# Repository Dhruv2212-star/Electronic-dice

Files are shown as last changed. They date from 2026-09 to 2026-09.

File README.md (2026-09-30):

# Electronic Dice
Tired of Board game tactics and cheating???? 
**I present an ELECTRONIC dice**  
A small 30mm x  30mm module which has 6 LEDs. when u press a button it changes LEDs quickly and random leds turn on from 1-6.  

# How to use?? 
It's simple enough for a todler to use ! just press a button and you get a random no. of LEDs!  
**Final assembly image**  

Assembly

*You know what else is cool??*
the PCB, it uses minimal components at surface to keep it super clean!  

PCB 3d model image

# Firmware Flashing
connect your debugger probe to the J2 port accordingly for this first.  
Our Pinc connections on PCB  

| J2 pin | Signal | ATtiny84A |  
| -----: | --- | --- |
| 1 | VCC | U1 pin 1  |  
| 2 | GND | U1 pin 14 | 
| 3 | MOSI | PB0 |  
| 4 | MISO | PB1 | 
| 5 | SCK | PB2 | 
| 6 | RESET  | PB3 |  

**Install Arduino IDE**  
then,  
File-> prefrences  
-additional board manager URLs  
--https://drazzy.com/package_drazzy.com_index.json  
Tools->Boards->Board manager  
install "ATTinyCore"  

Select our board by: Tools-> Board-> ATTinny84a  
then set:  
| Arduino setting | Value |  
| --- | --- |
| Chip | **ATtiny84A** |  
| Clock | **1 MHz internal** |  
| B.O.D. | **Disabled** |  
| EEPROM | **Retained** |  
| Programmer | **USBasp** |  

**Connect USBasp**  
(power the pcb off first)  
connect: USBasp -> J2  
**Burn the config**  
**Upload dice firmware**  

# That's it !!

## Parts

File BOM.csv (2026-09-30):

ref | value | quantity | symbol | footprint | unit_price_inr | supplier | buy_link | extended_price_inr
U1 | ATtiny84A-SSU | 1 | MCU_Microchip_ATtiny:ATtiny84A-SS | Package_SO:SOIC-14_3.9x8.7mm_P1.27mm | 80.54 | Evelta | https://evelta.com/attiny84a-ssu-ic-mcu-8bit-8kb-flash-14soic/ | 80.54
D1-D6 | White LED 1206 | 6 | Device:LED | LED_SMD:LED_1206_3216Metric_Pad1.42x1.75mm_HandSolder | 0.8 | KTRON India | https://www.ktron.in/product/smd-white-led-1206-package/ | 4.800000000000001
R1-R6 | 1kΩ | 6 | Device:R | Resistor_SMD:R_1206_3216Metric | 3.0 | Probots | https://probots.co.in/1k-smd-resistor.html | 18.0
R7 | 10kΩ | 1 | Device:R | Resistor_SMD:R_1206_3216Metric | 3.0 | Probots | https://probots.co.in/10k-smd-resistor.html | 3.0
C1 | 100nF 50V | 1 | Device:C | Capacitor_SMD:C_1206_3216Metric | 1.82 | KTRON India | https://www.ktron.in/product/100nf-50v-104-mlcc-1206/ | 1.82
SW1 | 6x6x5mm tactile push button | 1 | Switch:SW_Push | Button_Switch_THT:SW_PUSH_6mm_H5mm | 1.0 | Techtonics | https://techtonics.in/product/tactile-push-button-switch-4-pin-6x6x5-pack-of-10/ | 1.0
J1 | 1x2 2.54mm male header | 1 | Connector_Generic:Conn_01x02 | Connector_PinHeader_2.54mm:PinHeader_1x02_P2.54mm_Vertical | 1.37 | Sharvi Electronics | https://sharvielectronics.com/product-category/component/components/connectors/berg_strip/ | 1.37
J2 | 1x6 2.54mm male header | 1 | Connector_Generic:Conn_01x06 | Connector_PinHeader_2.54mm:PinHeader_1x06_P2.54mm_Vertical | 2.3 | Sharvi Electronics | https://sharvielectronics.com/product-category/component/components/connectors/berg_strip/ | 2.3
TOTAL |  |  |  |  |  |  |  | 112.83

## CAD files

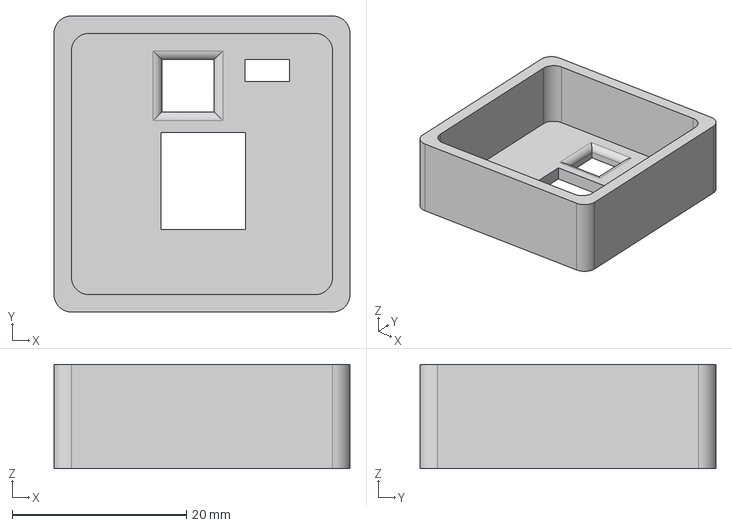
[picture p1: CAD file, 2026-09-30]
CAD/Top case.step
34.0 x 34.0 x 12.0 mm

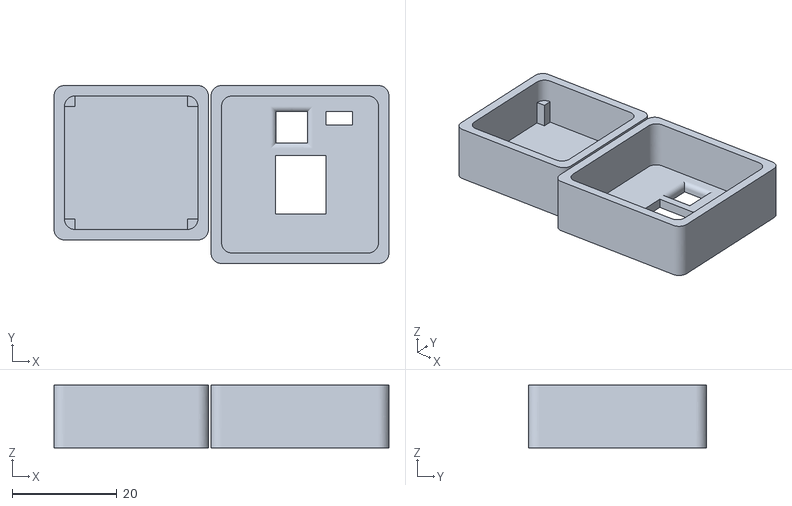
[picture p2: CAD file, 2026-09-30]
Production/Final case.stl
64.0 x 34.0 x 12.0

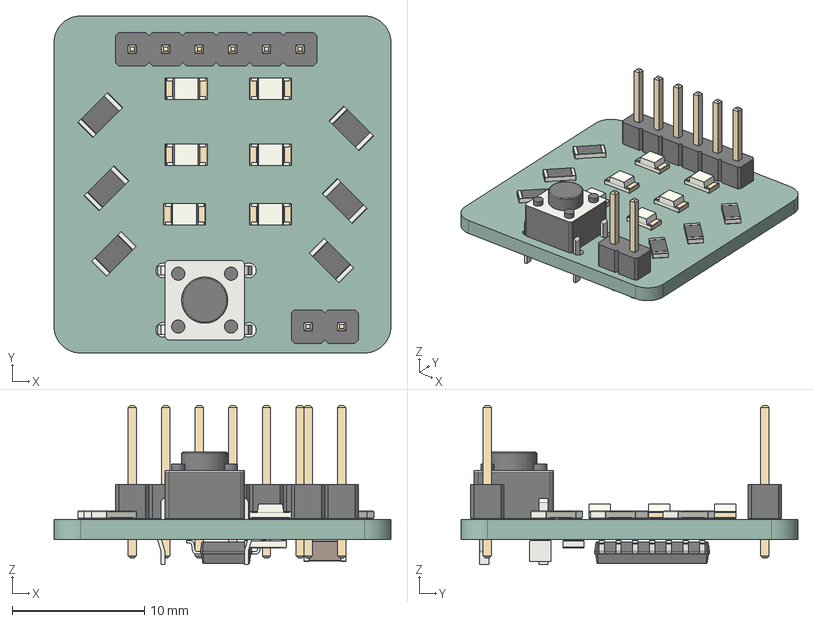
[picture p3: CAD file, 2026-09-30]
CAD/PCB model.step
25.5 x 25.5 x 12.0 mm
PinHeader_1x02_P254mm_Vertical
R_1206_3216Metric x 7
LED_1206_3216Metric x 6
SW_PUSH_6mm_h5mm
PinHeader_1x06_P254mm_Vertical
C_1206_3216Metric
SOIC-14_3.9x8.7mm_P1.27mm
module_PCB

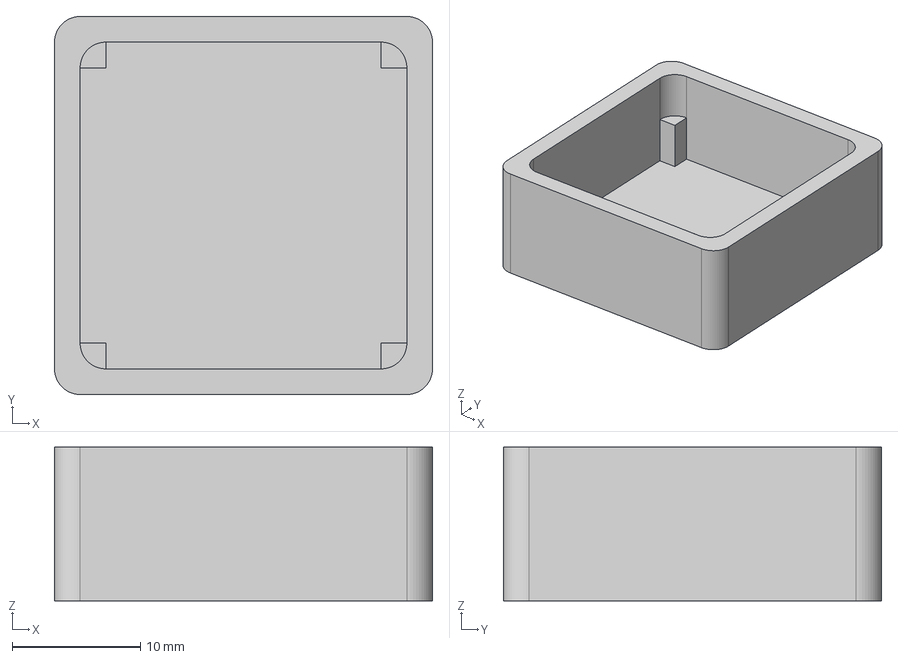
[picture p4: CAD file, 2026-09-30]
CAD/Bottom case.step
29.5 x 29.5 x 12.0 mm

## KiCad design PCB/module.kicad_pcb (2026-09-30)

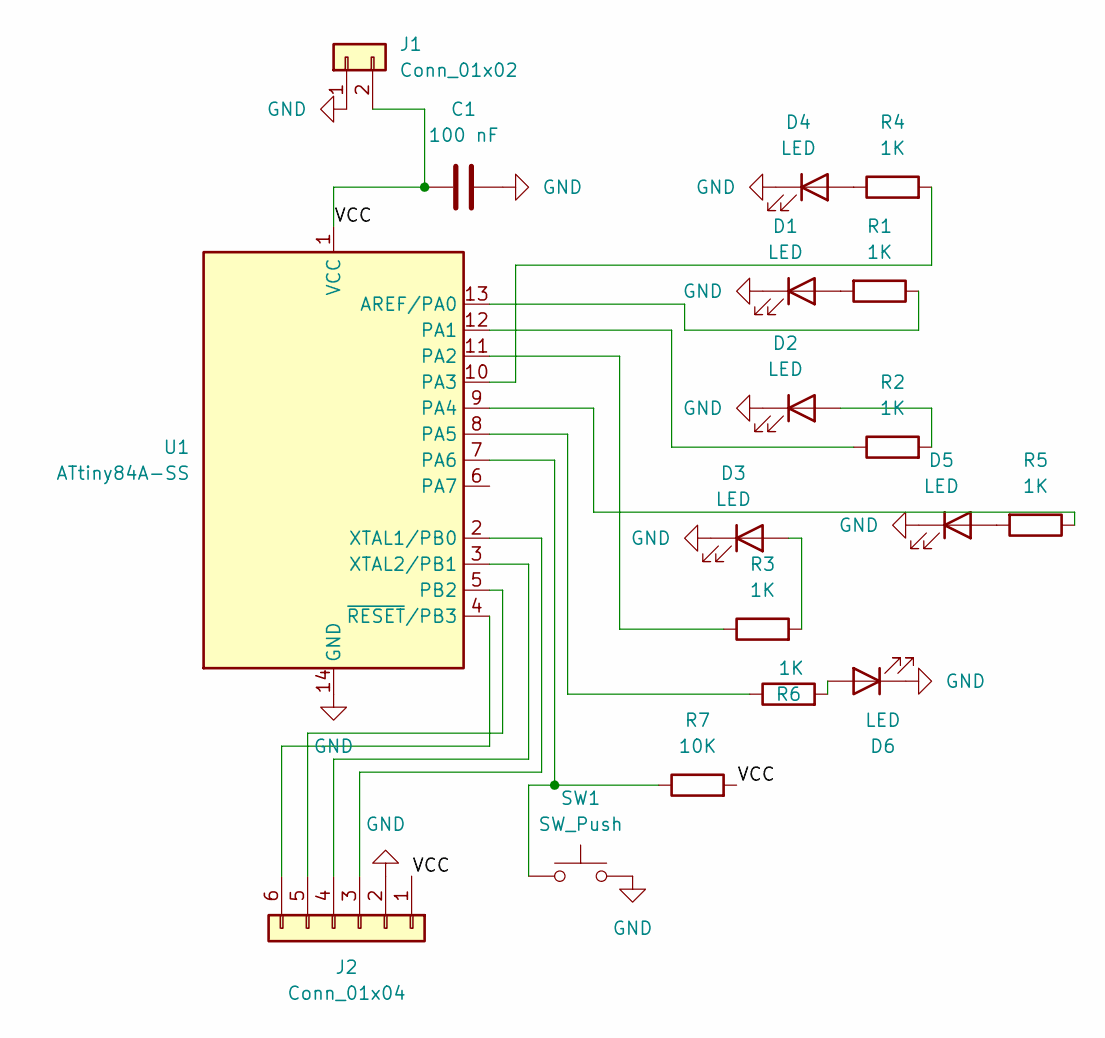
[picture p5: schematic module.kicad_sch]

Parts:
C1: 100 nF; C_1206_3216Metric
D1, D2, D3, D4, D5, D6: LED; LED_1206_3216Metric_Pad1.42x1.75mm_HandSolder
J1: Conn_01x02; PinHeader_1x02_P2.54mm_Vertical
J2: Conn_01x04; PinHeader_1x06_P2.54mm_Vertical
R1, R2, R3, R4, R5, R6: 1K; R_1206_3216Metric
R7: 10K; R_1206_3216Metric
SW1: SW_Push; SW_PUSH_6mm_H5mm
U1: ATtiny84A-SS; SOIC-14_3.9x8.7mm_P1.27mm

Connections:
/VCC: C1.1, J1.2, J2.1, R7.2, U1.1 (VCC)
GND: C1.2, D1.1 (K), D2.1 (K), D3.1 (K), D4.1 (K), D5.1 (K), D6.1 (K), J1.1, J2.2, SW1.2, U1.14 (GND)
unnamed: D1.2 (A), R1.2
unnamed: D2.2 (A), R2.2
unnamed: D3.2 (A), R3.2
unnamed: D4.2 (A), R4.1
unnamed: D5.2 (A), R5.2
unnamed: D6.2 (A), R6.2
unnamed: J2.3, U1.2 (XTAL1/PB0)
unnamed: J2.4, U1.3 (XTAL2/PB1)
unnamed: J2.5, U1.5 (PB2)
unnamed: J2.6, U1.4 (~RESET/PB3)
unnamed: R1.1, U1.13 (AREF/PA0)
unnamed: R2.1, U1.12 (PA1)
unnamed: R3.1, U1.11 (PA2)
unnamed: R4.2, U1.10 (PA3)
unnamed: R5.1, U1.9 (PA4)
unnamed: R6.1, U1.8 (PA5)
unnamed: R7.1, SW1.1, U1.7 (PA6)

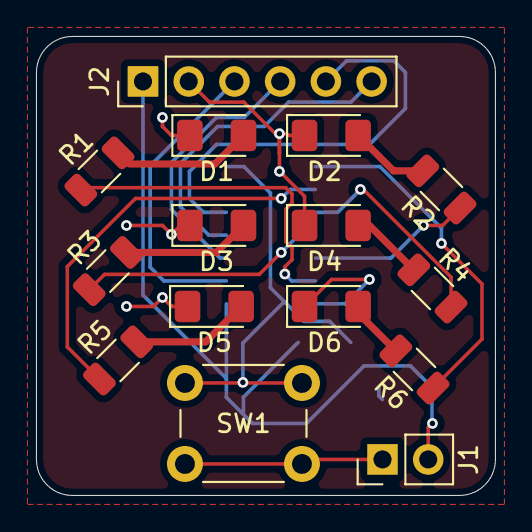
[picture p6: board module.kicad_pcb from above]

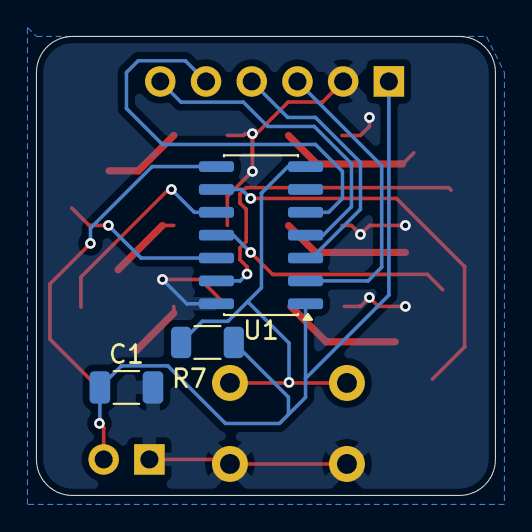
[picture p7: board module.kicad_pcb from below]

Board: 2 copper layers, 25.5 x 25.5 mm, 18 parts (3 on the bottom side), 19 nets.

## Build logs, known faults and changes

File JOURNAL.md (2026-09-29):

# Total time taken: 4 hours 10 mins 
# Initial design and research | 1 hour
Brain stormed about the things i wanted to make and deided to make an electronic dice where you press a button and get a random number  
from 1-6 just like a real dice but inform of LEDs on and off.  
**LED arrangement**  
X  X  
X  X  
X  X  
The reason why it took so much time is because i had to think of a way to make this dice and i had to go through a lot of choices  
where i even though of using classing 0.96 inch LED display fo display these numbers but it got too bulky.  
then i went through using a 3x3 matric LED to show the whole numbers but then it got too complicated.

# MCU selection | 30 mins  
Went with ATtiny84A because the initial mcu i slected (ATtiny85) was havinng just 6 gpio pins which was not possible to combine with 6 LEDs and a button. 
# PCB Completion | 1 hour 
Lapse: https://lapse.hackclub.com/timelapse/dIHN1J9NU4k6  

schematic
PCB tracing
PCB 3d model image

# Case | 1 hour 40 mins 
Lapse: https://lapse.hackclub.com/timelapse/vfHFLbeSQfqa
Assembly

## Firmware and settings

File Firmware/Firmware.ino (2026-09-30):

const uint8_t ledPins[6] = {
  PA0, PA1, PA2, PA3, PA4, PA5
};

const uint8_t buttonPin = PA6;

void showCount(uint8_t count) {
 
  for (uint8_t i = 0; i < 6; i++) {
    digitalWrite(ledPins[i], LOW);
  }

  
  uint8_t order[6] = {0, 1, 2, 3, 4, 5};

  for (int8_t i = 5; i > 0; i--) {
    uint8_t j = random(i + 1);

    uint8_t temp = order[i];
    order[i] = order[j];
    order[j] = temp;
  }

  for (uint8_t i = 0; i < count; i++) {
    digitalWrite(ledPins[order[i]], HIGH);
  }
}

void setup() {
  for (uint8_t i = 0; i < 6; i++) {
    pinMode(ledPins[i], OUTPUT);
    digitalWrite(ledPins[i], LOW);
  }

  pinMode(buttonPin, INPUT_PULLUP);

 
  randomSeed(analogRead(A7));
}

void loop() {
 
  if (digitalRead(buttonPin) == LOW) {

   
    delay(25);

    if (digitalRead(buttonPin) == LOW) {

      
      unsigned long startTime = millis();

      while (millis() - startTime < 2000UL) {
        uint8_t rollingCount = random(1, 7);
        showCount(rollingCount);

        delay(80);
      }

      
      uint8_t result = random(1, 7);
      showCount(result);

      
      while (digitalRead(buttonPin) == LOW) {
        delay(5);
      }

      
      delay(30);
    }
  }
}

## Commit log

2026-09-29 Update JOURNAL.md with project timeline and details
    Added total time taken and detailed progress updates for each phase of the project, including MCU selection and PCB completion.
2026-09-30 Development files of PCB and CAD
    [BOM.csv, Bottom case.step, Final case.stl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]
